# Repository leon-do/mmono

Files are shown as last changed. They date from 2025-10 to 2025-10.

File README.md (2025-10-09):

# Not All Edges Are Equal

Goal: Adjust depth based on edge radius.

This is an over-engineered mono hangboard pickup for climbing 🥑

## Dimensions





## Design

What is a 20 mm edge?

For a 90° angle, it’s simple.

For a perfect 90° angle, it’s simple—the distance (shown in red) is exactly 20 mm.



But a 90° edge is harsh on the skin. Sharp edges concentrate stress at a single point, increasing pain and the chance of skin splitting. That’s why all popular hangboards have rounded edges, called fillets in CAD.



> **Edge Fillet:** A smooth, curved surface with a constant radius that rounds off a sharp corner or transition between two intersecting faces.

Fillets are usually described by their **Edge Radius** — the larger the radius, the rounder the edge.



Unfortunately, there is no universal fillet radius for hangboards. Many manufacturers vary this (typically 3-10mm). Different brands use different edge radii:

| Brand / Board | Edge Depth | Edge Radius | Source |
|---|---|---|---|
| **Tension** | 10 mm | 3.175 mm (≈ 1/8") | [Tension Climbing](https://tensionclimbing.com/pages/hangboards) |
| **Crux Forged** | 20 mm | 6 mm | [Claw Hammer](https://www.instagram.com/reel/DLnMLajudYm/) |
| **Forma** | 20 mm | 6 mm | [Forma](https://www.instagram.com/reel/DPf8rRxDqC5) |
| **Lanta** | 20 mm | 7.5 mm | [Edgemaster](https://www.instagram.com/reel/DPQD1eZAqU_/?utm_source=ig_web_copy_link&igsh=MzRlODBiNWFlZA==) |
| **Beastmaker**  | 15-45 mm | 8 mm | [Test4Climbing](https://test4climbing.com/equipment-needed) |
| **Lattice** | 20 mm | 10 mm | [Climbing.com](https://www.climbing.com/skills/training/tom-randalls-guide-to-better-hangboarding-part-1/) |

> *Note: Needs more data but is hard to find.*

Where there is a fillet, the effective edge depth changes. What counts as “correct” depth (red lines)?

This might sound negligible, but millimeters matter for climbers.



To objectively define a true edge depth, we must agree on some definitions:



- **Total Depth:** The total depth, ignoring edge radius (90° diagram)  
- **Edge Radius:** The measurement of a curved edge  
- **Effective Length:** The usable length along its surface  
- **Ineffective Length:** The unusable length along its surface  
- **Effective Depth:** The usable depth of the edge  

Since there's no standard definition of Effective Length and Depth, the goal is to propose a mathematically *ok-ish* definition.

For a 90° angle, it’s simple. The red line is the usable edge. Your fingers hang there. The blue line is the unusable edge. Your fingers cannot hang there.



For a perfect right angle, the tangent of the corner is undefined, but if there's a small radius (0.01 mm), the tangent gradually transitions from horizontal to vertical, with the midway point at 45°. 



Based on this, we can define the **Effective Length** as the distance along the edge up to this midway point of the fillet.



Now that Effective Length is defined, we can calculate **Effective Depth**.



Use the unit circle as a reference.



Given Edge Radius & Effective Depth, calculate Total Depth:

```
Set edge_radius (blue) = 8mm
Set effective_depth (dotted) = 20mm

Solve for total_depth (green)

red_line = cos(45) * 8mm
pink_line = edge_radius - red_line

total_depth = effective_depth + pink_line
green = dotted + pink
```



A one line equation

```
total_depth = effective_depth + (edge_radius * (1 - cos(45))

total_depth = effective_depth + (edge_radius * (1 - 0.5 ** 0.5))
```

Python

```python
import math

effective_depth = 20

edge_radius = 8

total_depth = effective_depth + (edge_radius * (1 - 0.5 ** 0.5))

print(total_depth)
# total_depth = 22.34314575050762
```

Finally, use calculated Total Depth to extrude your mono



Then create your Fillet Radius.



**Conclusion:**  
A **22.343 mm deep mono + 8 mm fillet radius** gives exactly **20 mm effective edge depth**.

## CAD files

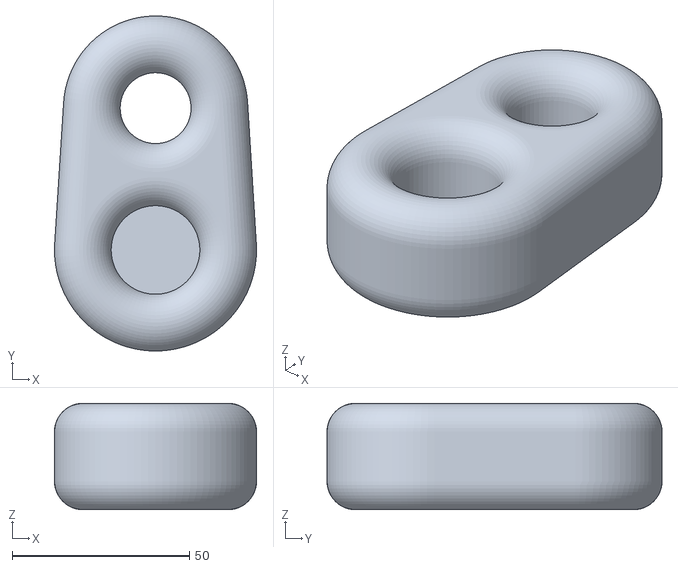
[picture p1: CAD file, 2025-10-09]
mmono.stl
57.0 x 94.5 x 30.0

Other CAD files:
mmono.f3d

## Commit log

2025-10-08 adjust size
    [mmono.f3d, mmono.stl, mono-20mm.stl]
2025-10-09 16mm top hole
    [mmono.f3d, mmono.stl]
2025-10-09 20mm top
    [mmono.f3d, mmono.stl]
